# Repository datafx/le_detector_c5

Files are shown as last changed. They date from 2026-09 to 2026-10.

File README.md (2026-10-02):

# LE Gear Detector — XIAO ESP32-C5 Fork

Passive 5GHz/2.4GHz WiFi + BLE scanner for law-enforcement equipment,
rebuilt for the Seeed XIAO ESP32-C5 to add 5GHz detection. The original
project ([`datafx/le_detector`](https://github.com/datafx/le_detector),
ESP32-WROOM-32U) is 2.4GHz only and can't see the highest-value target
found in the field: Axon Fleet Hub units broadcasting their own hidden APs
on 5GHz. A match signals with a flashing red screen border + buzzer,
faster as the signal strengthens.

## Hardware

| Part | Notes | Link |
|---|---|---|
| Seeed Studio XIAO ESP32-C5 | RISC-V, dual-band WiFi 6 (2.4+5GHz), BLE 5, USB-C | [Seeed Studio](https://www.seeedstudio.com/Seeed-Studio-XIAO-ESP32C5-p-6609.html) |
| 2.8" ILI9341 TFT, SPI, 240×320, with XPT2046 touch + microSD slot | Standard combo board sold under many names; touch and SD are present on the board but not yet used by this firmware | search "2.8 inch ILI9341 SPI touch SD" |
| Active buzzer module, 3-pin (VCC/GND/signal) | Must have its own driver transistor onboard. Confirmed **active-low** on this build — check `BUZZER_ACTIVE_LOW` in `config.h` against yours | search "active buzzer module 3 pin" |
| Alfa APA-M25 dual-band antenna | 8 dBi @2.4GHz / 10 dBi @5GHz, RP-SMA | [Alfa Network](https://alfa-network.eu/apa-m25) |
| U.FL → RP-SMA pigtail | Connects the XIAO's onboard U.FL to the external antenna | search "U.FL RP-SMA pigtail" |
| Breadboard + jumper wires | | |
| USB-C cable | Power + programming | |

The display, buzzer, and pigtail are generic commodity parts sold by many
sellers under many names — there's no single canonical listing worth
linking (and one that works today can vanish tomorrow), so a search term
is given instead of a storefront link.

## Wiring

Pin assignments confirmed against the physical board — see `CLAUDE.md`
decision #6 for the full reasoning, including which pins were deliberately
avoided and why (boot-strap pins, reserved for a future GPS UART, etc.).

| Signal | XIAO pin | GPIO | Notes |
|---|---|---|---|
| Display `VCC` | `5V` | — | needs the 5V/VBUS pin specifically, not `3V3` |
| Display `GND` | `GND` | — | |
| Display `LED` (backlight) | `5V` | — | tied permanently on |
| Display `CS` | `D2` | 25 | |
| Display `DC` | `D3` | 7 | |
| Display `RESET` | `D4` | 23 | |
| Display `SDI`/MOSI | `D10` | 10 | shared SPI bus |
| Display `SCK` | `D8` | 8 | shared SPI bus |
| Display `SDO`/MISO | `D9` | 9 | shared SPI bus |
| `SD_CS` | `D5` | 24 | wired and reserved — SD support isn't built yet |
| `SD_MOSI`/`SD_MISO`/`SD_SCK` | `D10`/`D9`/`D8` | 10/9/8 | shared with the display |
| Buzzer `VCC` | `3V3` | — | |
| Buzzer `GND` | `GND` | — | |
| Buzzer signal | `D0` | 1 | |

Touch (`T_CLK`/`T_CS`/`T_DIN`/`T_DO`/`T_IRQ`) is present on the display
board but intentionally unwired — planned for future bench-configuration
tooling, not for driving controls.

## Build & flash

PlatformIO has no ESP32-C5 support as of this writing — this project
builds via the Arduino IDE / `arduino-cli` instead.

### Arduino IDE

1. **Install the ESP32 board package.** File → Preferences → Additional
   Boards Manager URLs, add:

       https://raw.githubusercontent.com/espressif/arduino-esp32/gh-pages/package_esp32_index.json

   Then Tools → Board → Boards Manager, search "esp32", install **esp32 by
   Espressif Systems**, version **3.3.5 or higher** (built and tested
   against 3.3.11).

2. **Select the board:** Tools → Board → esp32 → **XIAO_ESP32C5**.

3. **Install libraries** via Library Manager: `Adafruit GFX Library`,
   `Adafruit BusIO`, `Adafruit ILI9341`. BLE support is bundled with the
   esp32 core itself — no separate BLE library install needed.

4. **Open the sketch:** `firmware/le_detector_c5/le_detector_c5.ino`.
   Every `.cpp`/`.h` file in that same folder is compiled and linked
   automatically — Arduino sketches don't use PlatformIO's `src`/`include`
   split, so everything lives flat in one folder.

5. **Plug in the board** via USB-C, select its port, and upload.

### arduino-cli

    arduino-cli core update-index
    arduino-cli config set board_manager.additional_urls https://raw.githubusercontent.com/espressif/arduino-esp32/gh-pages/package_esp32_index.json
    arduino-cli core install esp32:esp32@3.3.11
    arduino-cli lib install "Adafruit GFX Library" "Adafruit ILI9341"
    arduino-cli compile --fqbn esp32:esp32:XIAO_ESP32C5 firmware/le_detector_c5
    arduino-cli upload -p /dev/ttyACM0 --fqbn esp32:esp32:XIAO_ESP32C5 firmware/le_detector_c5

### If upload fails, or the board doesn't show up as a serial port

The C5 uses its SoC's own native USB-Serial/JTAG peripheral, not a separate
USB-serial chip — no CH340/CP210x driver needed — but that comes with its
own gotchas, all hit and resolved during this project's own bring-up:

- **Linux: the `cdc_acm` kernel module.** If `/dev/ttyACM0` never appears,
  check `lsmod | grep cdc_acm`; if missing, `sudo modprobe cdc_acm` (if
  *that* fails with "module not found," your running kernel doesn't match
  what's installed on disk — reboot). Your user also needs permission on
  the port: group `dialout` on Debian/Ubuntu, `uucp` on Arch-based distros.
- **Upload fails with "Invalid head of packet" or "Serial data stream
  stopped: possible serial noise or corruption."** Looks like a code or
  board problem, usually isn't — a USB hub between the board and the
  computer was the actual cause here. Plug directly into a root/motherboard
  port before suspecting anything else.
- **No serial monitor output.** `arduino-cli monitor` produced nothing in
  testing even with the board clearly running. On Linux, plain
  `cat /dev/ttyACM0` worked reliably instead, and conveniently triggers a
  fresh reset on open. This firmware doesn't print anything during normal
  operation anyway (the display is the real status output), so this mostly
  matters if you're debugging.

## Watchlist

**62 OUI entries** across law-enforcement radio, body/dash cam, vehicle
router/MDT, radar/lidar, ALPR, and lightbar equipment, plus **6 SSID
patterns** (5 real + one test/demo row). The full list, provenance, and
vendor-collision reasoning live as comments in the source files themselves
— those are what actually runs, so they're the version that can't drift out
of sync with reality:

- [`oui_table.cpp`](firmware/le_detector_c5/oui_table.cpp) — MAC OUI
  watchlist
- [`ssid_table.cpp`](firmware/le_detector_c5/ssid_table.cpp) — SSID
  watchlist (beacons, probe requests, probe responses)

A few vendors are **disabled by default** after field testing showed they
false-positive more than they help — commented out, not deleted, so each
is one edit away from re-enabling if that read ever turns out wrong:
**CradlePoint**, **Peplink**, **Pepwave**, **Vantiva**, **PRO-VISION**.
Comment a row back in (or out) to change what's active for most entries;
CradlePoint specifically is gated by an `EXCLUDE_VENDOR_CRADLEPOINT` toggle
at the top of `oui_table.cpp`. Run `test/test_oui.cpp` after any edit.

Want to test a local addition before submitting it upstream? Drop it in
`user_oui_table.cpp` instead — unsorted, just appended to.

### SSID watchlist

| Pattern | Label | Category |
|---|---|---|
| `PSP-MVR` | PSP in-car video | Body/car cam |
| `SP-MVR` | PSP paired virtual AP | Other |
| `PSP-TEST` | PSP facility | Other |
| `PSPWLAN` | PSP facility | Other |
| `PSP_UC` | PSP facility voice | Other |
| `LEDET-TEST` | TEST/DEMO — not real gear | Other |

All PSP rows are prefix matches, deliberately — a substring `CONTAINS
"PSP"` rule tested against real survey data matched several unrelated
civilian networks near the same facilities (a pet store, a retailer, a
private residence). The full prefix string, not the shared `PSP` fragment,
is what makes these safe to alert on. Same logic for `SP-MVR` vs.
`PSP-MVR`: kept as two explicit rows rather than one `CONTAINS "SP-MVR"`
rule, which would also match `PSP-MVR` (it contains "SP-MVR" as a
substring).

**Provenance:** confirmed via WiGLE survey data cross-checked against
three independent Pennsylvania State Police barracks in three different
troops, roughly 280km apart, all on matching Cisco hardware.
`PSP-MVR`/`SP-MVR` (Mobile Video Recorder, PSP's in-car video system) and
`PSP-TEST` were confirmed at all three sites; cross-site BSSID correlation
— matching Cisco OUI sub-ranges across independently surveyed locations,
not just a shared naming convention — confirms a single statewide
deployment, not coincidence. `PSPWLAN`/`PSP_UC` were observed at one site
only, so carry lower confidence until cross-checked elsewhere. Exact survey
locations and dates are kept in local, non-public notes rather than this
file.

**Known limitation:** these are fixed APs at barracks buildings, not
vehicle-mounted equipment. A hit on the road means a cruiser's in-car
client is directedly probing for one of these SSIDs while out of range of
the real AP — whether PSP in-car systems actually do that is untested in
the field. Treat a hit here as barracks-proximity, not confirmed mobile
detection, until that's verified.

## How detection works

A three-band phase machine — only one of WiFi-5GHz / WiFi-2.4GHz / BLE can
be up at a time (one radio behind a dual-band diplexer, and it can't do
WiFi and BLE simultaneously either). Scheduling is 5GHz-dominant, based on
real drive data and a measured radio-switch cost on this specific board:

- **5GHz** sweeps continuously (9 non-DFS channels, ~2.7s/sweep) — the
  only long-range, continuous signal (beacons every ~100ms), and the
  primary detection path.
- **BLE** gets a short 400ms dip every 3rd 5GHz sweep, not every cycle —
  its realistic job is a close/stopped encounter lasting several seconds,
  not a sub-second highway pass, so it doesn't need constant attention.
- **2.4GHz** gets a brief 3-channel token check (1/6/11 only) every 8th
  sweep — contributes almost nothing on the road per the drive data (a
  barracks-proximity signal, not a mobile one), kept only as an occasional
  check.

Measured WiFi↔BLE switch cost on this board: **103ms** to switch into BLE,
**9ms** back out, with zero measured variance across repeated runs. See
[`firmware/05_radio_switch_timing/`](firmware/05_radio_switch_timing/) to
re-measure on different hardware. The "every N sweeps" cadence constants
(`BLE_EVERY_N_SWEEPS`, `WIFI_2G_EVERY_N_SWEEPS` in `config.h`) are starting
points to tune empirically, not a measured optimum.

A match's alert shows which band/radio caught it — e.g. "via 5GHz WiFi
OUI" or "SSID beacon (2.4GHz): PSP-MVR" — useful for telling a long-range
hit apart from a close BLE encounter at a glance.

## Known limits

- **One radio, three bands, time-sliced.** Only one of 5GHz WiFi / 2.4GHz
  WiFi / BLE is ever listening — during any other phase, that band is
  invisible. See "How detection works" above for the current schedule.
- **MAC randomisation.** Only public BLE addresses and non-randomised WiFi
  MACs carry a real OUI — randomised addresses are skipped, since their
  vendor bits are meaningless. SSID matching runs independently of this
  and is unaffected.
- **PSP SSID rows are barracks-proximity, not confirmed mobile detection.**
  See SSID watchlist provenance above.
- **SSID matching depends on what's actually broadcast.** A wildcard probe
  or hidden-SSID beacon carries no SSID bytes at all — nothing to match
  either way. Directed probe requests are a declining signal on modern
  phones (randomised MAC + wildcard probes only, roughly iOS/Android 2014-
  2017 onward), so this increasingly only catches older/embedded clients.
  Beacon/probe-response matching is unaffected by that trend.
- **No SD card support yet.** The display board has a microSD slot and the
  select pin (`SD_CS`) is wired, but CSV-based config/logging isn't built —
  the firmware runs entirely on its compiled-in tables for now.

## Tuning

Everything lives in `firmware/le_detector_c5/config.h`: band/channel
lists, sweep cadence, flash-rate endpoints (`RSSI_WEAK`/`RSSI_STRONG`,
`FLASH_PERIOD_SLOW`/`FAST`), alert hold time, and `BUZZER_ENABLED` for
silent bench testing.

## License

GPLv3 (see `LICENSE`), matching the companion `rf_stalker` and
`police_oui_watchlist` projects, and the upstream `le_detector` project
this is forked from.

[`firmware/le_detector_c5/detector.cpp`](firmware/le_detector_c5/detector.cpp)
carries its own `SPDX-License-Identifier: MIT` line for the portions
adapted from nyanBOX — see the header comment in that file for exactly
what was adapted and what changed. Everything else in this repo is GPLv3.

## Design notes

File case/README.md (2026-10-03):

# Case — WORK IN PROGRESS, NOT FINAL

3D-printable enclosure (Tinkercad export), built and tested with the
display/XIAO/buzzer wired via breadboard jumpers — confirmed everything
fits and works, but this is not the final case.

- `Extended_case.stl` / `Lid.stl` — current working revision.
- **Width and height are final** (matched to the display's own 50×86mm
  board, with the lid already cut with a viewing window for it).
- **Depth will be shortened** once the carrier PCB (see
  `../hardware/carrier_pcb/`, also still WIP) is finished and the actual
  component stack height is known — the current depth has far more
  clearance than needed.

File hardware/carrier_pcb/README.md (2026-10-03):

# Carrier PCB — WORK IN PROGRESS, NOT FINISHED

Do not fabricate this board as-is. Schematic, footprint layout, and
routing are all DRC-clean (0 errors, 0 unconnected items) - routing was
redone from scratch after U1's footprint was corrected (see below), and
solder-side correctness for all 4 connectors was verified directly from
the footprint layer data, not just visually. Still no physical test-fit
of the current board size - see "What's NOT done."

## Mounting: held by the header, not screwed to the case

This board has **no mounting holes**. Earlier drafts gave it the same 4
holes as the display module, so it could bolt to the case's existing
corner bosses — but that only works by stacking both boards on the same
4 screws, which needs standoffs/spacers between them and a case
modification to deepen the bosses. Given how light this assembly is
(PCB + XIAO + buzzer), that's not worth it: the board is instead held
purely by its header engagement with the display board above it (which
keeps screwing to the case exactly as it did before this board existed).
If real-world vibration ever proves that insufficient, a dab of hot glue
between the two boards is the cheap fix — not designed in up front.

**History: chamfer → notch → narrowed board, each one fitting the real
case better than the last.** The first version used a 6mm diagonal
chamfer at each corner, sized off the display's datasheet hole margins
with no real measurement of the boss itself. A 1:1 scale printout
test-fit against the real case showed it wasn't close - the boss is a
rounded square, not the slim post the chamfer assumed. Measured it
properly off the case STL (top-down render, self-calibrated against the
model's own exact bounding box, not an assumed scale): roughly **7-8mm
across**. Switched to a square notch sized as large as the layout
allowed (7.3mm, capped by J1's own pad clearance) - still about 1mm
short of what the boss needed, an acknowledged unresolved gap at the
time.

**Resolved differently: don't dodge the bosses, don't reach them at
all.** User measured the case's actual clear channel between the two
bosses directly: **36.3mm wide** (the board's full 86mm length is fine,
the case was never tight there). The board became a **plain rectangle,
36.3mm × 86mm**, centered on J1 (which is the single widest feature at
33.02mm) rather than matching the display's full 50mm width. This
sidesteps the boss problem entirely instead of cutting around it - no
corner notches needed, and it also incidentally resolved a DRC
clearance warning on a user-routed TFT_SCK trace that had been sitting
close to the old, bigger notch. J1 keeps 1.04mm of copper-to-edge
clearance on each side (comfortably above the 0.5mm minimum), and J2/U1/
J3 were already well inside this narrower footprint with no changes
needed.

**Trimmed again: top edge pulled in to put J2 right on the edge too,
mirroring J1.** J1 sits 2.0mm (pin-center-to-edge) from the bottom edge.
J2 was still 4.96mm from the top edge, leaving unused board above it.
Pulled the top edge in to the same 2.0mm margin: new top edge at
**y=2.96** (was y=0), so the board is now **36.3mm × 83.04mm**. J2 gets
the same 1.40mm copper-to-edge clearance J1 already had. Both edits
(width and this height trim) were applied by editing the outline
directly in the routed file rather than regenerating from the script,
each time confirming no existing trace/via fell outside the new
boundary before committing to it - preserved all 64 of the user's
hand-routed segments through both changes, verified via DRC (0 errors)
each time.

**Still not physically confirmed** - this is a digital fit against the
user's own case measurement, not yet a hands-on test with the actual
board at its current size. Print and test-fit again before fabricating.

## U1 (XIAO socket): footprint was wrong, now matches the real device

The original U1 footprint was a generic guess — two rows of 7 pins,
7.62mm apart, pins at `i*2.54mm` within each row — never checked against
the real XIAO ESP32-C5's actual pinout, and not mirrored for back-side
mounting. User caught both problems: wrong footprint, and backwards for
how the device actually gets plugged in (XIAO mounts on the board's
back, opposite the display).

**Fixed using Seeed's own official files**, not another guess:
downloaded their published KiCad footprint
(`XIAO-ESP32-C5-DIP.kicad_mod`) and schematic symbol from the
[XIAO KiCad library](https://wiki.seeedstudio.com/XIAO_BLE/) (same
family covers every XIAO board). The real footprint has **15.24mm**
between the two pin rows, not 7.62mm — a completely different part of
the board was being used. Cross-referenced the symbol to get the
real pin-number-to-signal mapping (D0–D6 on one row, D7–D10 + 3V3_OUT/
GND/VBUS on the other, in that specific order — not a clean split).

**Mirroring**: a part mounted on the back layer needs its footprint
mirrored left-right relative to how it would sit on the front — this is
what KiCad does automatically when you flip a footprint in the GUI, but
since this one was hand-authored as raw coordinates, that mirroring had
to be applied by hand too, and wasn't. Verified the mirror direction
using Seeed's own front and back pinout diagrams for the XIAO (they
publish both specifically because this flip is easy to get backwards) -
confirmed the two diagrams are exact left-right mirrors of each other
before trusting the derivation.

**Routing cleared, not preserved, for this one.** Unlike the earlier
outline-only changes (width, height trims), this moves the pads
themselves, and nearly every net touches U1 directly or routes through
it - preserving any of the old routing wasn't realistic. Pulled all 64
track/via segments rather than leave something uncertain in place.
Board is back to a clean, DRC-verified ratsnest (0 errors, 12
unconnected items, matching the exact pre-routing baseline) - **needs a
full re-route**.

**Slid toward the board's right edge** for USB-C cable clearance, as
far as the *real device's physical body* allows - not just its pads.
The pads alone would have permitted sliding further right, but the
actual XIAO module extends ~2.8mm beyond its own pin span on each side;
checking pads only would have let the real part hang ~1.3mm off the
board edge. Capped at **x=32** (board right edge minus the real
courtyard extent minus a 0.5mm margin), not x=34.

**Flagging, not deciding, one open question**: with this as a straight
slide (no rotation), the XIAO's USB-C port faces *inward* (toward
x≈21-23, the board's open left-center area), not toward the right edge
itself - it's the *blank far end* of the device that now sits near the
right edge. This still frees up real approach space for a cable (the
whole left side of U1's row is now open board), but if the port itself
needs to be at/past the edge, that needs a 180° rotation on top of the
slide, which hasn't been done - flagging it rather than guessing, since
it changes which end of the board needs clearance.

## J3 (buzzer socket): pin order changed, moved left, now a right-angle header

**Pin order**: was VCC/GND/SIG (pins 1/2/3). Changed to **GND/SIG/VCC**
(pins 1/2/3) to match the physical pinout of the actual buzzer module
being used. Schematic symbol's pin names updated to match (so the
symbol doesn't show "pin 1 = VCC" while actually wired to GND) - J3's
physical pad *positions* didn't change for this part, only which net
each pad carries.

**Position**: moved from x=20 to **x=9** (pins span 9.00-14.08), clear
of both the board's left edge (1.55mm pad clearance) and U1's real
device body (6.77mm clear of U1's courtyard at x≈21.45) - U1 having
moved right made room for this.

**Right-angle (90°) header, not straight** - so the buzzer module can
lie flat against the back of the carrier instead of standing up
perpendicular on pins. This is a BOM/part-choice change, not a PCB
layout change: a right-angle header's hole pattern is the same 3 pads
at the same pitch, just a different physical part populated there -
reflected in `BOM.md`, `bom.csv`, and the schematic's own description
field for J3.

**Standoff height: not chosen - a real open question, not a guess I'm
comfortable making.** The buzzer board needs to lie flat without
touching a USB-C cable plugged into U1's port. Getting that number
right needs several real measurements I don't have verified: U1's own
header standoff height (never specified - it's just "a 2x7 female
header" with no particular part/height chosen either), the XIAO's USB-C
receptacle height above its own PCB (datasheet has no Z-axis dimension,
only the 21x17.8mm footprint), and critically, **the actual cable's
plug profile** - which isn't a XIAO spec at all, it varies by which
cable gets used, from slim low-profile plugs to bulky ones. A header
spec sheet can't tell me that part. **Recommend a physical mockup**
once the real parts are in hand (XIAO + a header + the actual cable
likely to be used) rather than trusting a number derived from
incomplete datasheets - or tell me the exact cable/header part numbers
if there's a specific one in mind and I can look up real dimensions for
those two at least.

## J2 (SD header socket): populated, not wired

J2 is on the board purely so the display module has somewhere to plug
its SD header into for mechanical support — pulling one corner of the
display without it would leave that corner unsupported by anything but
J1. It carries **no electrical connections**: all 4 pins (and U1's
SD_CS pin, which would otherwise drive it) are explicit no-connects.
SD card bring-up (mount, read, CSV config/logging) is a real future
goal, not abandoned, but it's down the road enough that wiring it now
would just be unused complexity - revisit as part of a later PCB
revision, likely alongside touch support.

**The display doesn't come with a header there to plug in** - the
MSP2807's SD pads ship unpopulated (confirmed from the datasheet). A
1×4 male header needs to be hand-soldered onto the display board itself
before it has anything to mate with J2 - added to `BOM.md`.

**Position re-measured and corrected.** The first placement (18.40,
11.00) was a rough visual estimate. Re-measuring the datasheet image
found the estimate was based on an incorrect pixel-to-mm scale (assumed
a literal 1:1 300dpi-to-mm render; the PDF's actual scale, derived from
the two known hole-spacing dimensions, is ~9.05px/mm, not ~11.81).
Corrected position: **(21.15, 4.96)** — the 4 SD pads sit at essentially
the same height as the top mounting holes, not ~11mm down as first
estimated. Pitch was already right (standard 2.54mm). Still a datasheet
*image* measurement, not a direct physical check — reasonably confident
now, but confirm against the real board before fabricating.

## Silkscreen: functional labels, pin-1 markers, and a real bug fixed

Added on request - before this, silkscreen was just 4 bare reference
designators (J1/J2/J3/U1), nothing else, no graphics at all.

- **Functional labels** on all 4 connectors, stating what they are *and*
  which side of the board the part goes on: `DISPLAY — FRONT` (J1),
  `SD (NC) — FRONT` (J2), `XIAO — BACK` (U1), `BUZZER — BACK` (J3).
- **Pin-1 markers**: pin 1 of every connector is now a square pad
  instead of round (standard convention) - J2 and J3 didn't strictly
  need it since they're asymmetric/small, but did it for all 4 for
  consistency and because this board has already had two real
  orientation bugs this session (U1's mirroring, J3's pin order) - cheap
  insurance against a third one during assembly.
- **Board title**: `LE Detector C5 by datafx`, 2.2mm text (noticeably
  larger than the 1mm connector labels), vertical along the left edge,
  top-justified. Placed on the back (B.SilkS) rather than the front -
  the display covers nearly the full front face once plugged into J1
  (its own board is as tall as this carrier, header near its bottom
  edge), so front silkscreen would be hidden after assembly; the back
  stays mostly open even with U1/J3 populated. Positioned clear of both
  U1 and J3, confirmed via DRC and a true flipped-back render (not just
  the see-through view) before trusting it, per the mirroring lesson
  just below.

**Found and fixed a real bug while verifying this, not a new one
introduced by it: back-layer silkscreen text was never actually
mirrored.** DRC has been flagging `nonmirrored_text_on_back_layer` on
U1's and J3's reference labels since they were first created, and it
was dismissed every single time as the same cosmetic baseline as the
`lib_footprint_issues` warnings - it isn't. Rendered the board with
`kicad-cli`'s `-m` flag (true "physically flip the board and look at
the back" view, not the usual "see-through from the front" renders used
throughout this project) and the text came out genuinely backwards -
`U1`, `J3`, and both new back-side labels all read right-to-left,
garbled. This would have printed wrong on the real board. Fixed by
adding `(justify mirror)` to all 4 back-layer text elements (the 2
existing reference labels plus the 2 new functional labels) - verified
again with the same true-flip render, now reads correctly. **Re-check
any future back-layer text added to this board the same way** (render
with `-m`, don't trust the normal see-through view) - this bug is easy
to reintroduce since hand-authored S-expressions don't get KiCad's
automatic GUI-flip mirroring for free.

## What's done and verified

- **Schematic** (`carrier_pcb.kicad_sch`) — complete, ERC-clean (0 errors).
  Every net matches the locked pin table in the project's own notes.
- **PCB footprint placement** (`carrier_pcb.kicad_pcb`) — board outline
  (36.3×83.04mm rectangle, see above) and the display's main header
  position taken directly from the MSP2807 display's own datasheet, not
  estimated. DRC-verified: every pad is on the correct net
  (ratsnest-correct), 0 real errors.
- **U1 footprint** now matches Seeed's official XIAO-ESP32-C5-DIP
  footprint, correctly mirrored for back-side mounting (see above).
- **Silkscreen** — functional labels + pin-1 markers on all 4
  connectors, back-layer text verified correctly mirrored (see above).
- **Routing** — redone from scratch in the KiCad GUI after U1's
  footprint was corrected. DRC clean: 0 errors, 0 unconnected items.
- **Solder side for all 4 connectors** — verified directly from each
  footprint's stored layer field (not just visually): J1/J2 on `F.Cu`
  (front), U1/J3 on `B.Cu` (back), matching their silkscreen labels.

## What's NOT done

- **SD header position** (J2) is re-measured and corrected (see above)
  but still a datasheet-image measurement, not a direct physical check —
  verify against the physical display board before finalizing.
- **No future USB-C panel connector or pigtail** designed yet — the case
  already has a wire-passthrough cutout reserved for this, but the
  connector and cable routing aren't part of this board yet.
- **No physical test-fit yet** against the real case/display with the
  *current* (narrowed) outline — sized against the user's own case
  measurement (36.3mm clear channel), not yet confirmed hands-on with
  the actual board.

## Fits the case in `../../case/` (also WIP — see its README)

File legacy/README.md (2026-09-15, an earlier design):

Original ESP32 / 2.4 GHz-only / u8g2-OLED implementations of `detector.cpp`,
`ui.cpp`, `main.cpp`, and `config.h`, carried over from `le_detector` for
reference only. These need a genuine rework for the XIAO ESP32-C5 (5 GHz
support, three-band phase machine, ILI9341 colour UI, SD-backed config) per
the root `CLAUDE.md` — not a port. Do not build against this directory.

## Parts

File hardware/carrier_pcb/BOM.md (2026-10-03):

# Carrier PCB — Bill of Materials

## Parts to populate on the carrier PCB

Generated from the schematic (`kicad-cli sch export bom`) — see `bom.csv`
for the raw export.

| Ref | Qty | Description |
|---|---|---|
| J1 | 1 | 1×14 female header, 2.54mm pitch — socket for MSP2807 display main header |
| J2 | 1 | 1×4 female header, 2.54mm pitch — socket for MSP2807 SD header (**mechanical only, not wired** — see README) |
| J3 | 1 | 1×3 **right-angle (90°)** female header, 2.54mm pitch — socket for 3-pin active buzzer module, lets the buzzer board lie flat against the carrier instead of standing up on pins. **Standoff height not yet chosen** — must clear a USB-C cable plugged into U1, see README. |
| U1 | 1 | 2×7 female header, 2.54mm pitch — socket for Seeed XIAO ESP32-C5 |

## Mounting hardware

None. This board isn't screwed to the case — it's held by the header
engagement with the display board above it, which keeps its own original
4 screws/standoffs into the case's corner bosses unchanged. A dab of hot
glue between the carrier PCB and the display board is the fallback if
testing ever shows the header connection alone isn't enough — not
included here since it's a maybe-needed-later item, not a planned part.

## Plug-in modules (not populated on the carrier PCB)

These mate with the sockets above rather than being soldered to the
carrier board. Already documented with sourcing links in the project
[README](../../README.md#hardware) — not duplicated here to avoid two
copies drifting out of sync:

- Seeed Studio XIAO ESP32-C5 → plugs into U1
- MSP2807 2.8" display module → plugs into J1 + J2 (see below — J2's
  side needs a header added to the display board itself first)
- 3-pin active buzzer module → plugs into J3

## Parts needed on the display module itself (not included with it)

| Part | Qty | Notes |
|---|---|---|
| 1×4 male header, straight, 2.54mm pitch | 1 | The MSP2807 ships with its SD-header pads **unpopulated** — confirmed from the datasheet, this isn't a stock part of the board. Hand-solder one onto those pads so the display has pins to plug into J2. Purely mechanical (J2 carries no signals — see README); any 1×4 straight male header works, doesn't need to match any particular spec beyond 2.54mm pitch to fit the pads. |

## Not yet in this BOM

- Future USB-C panel-mount connector + internal pigtail cable (per the
  wire-passthrough cutout already in the case) — not designed yet.

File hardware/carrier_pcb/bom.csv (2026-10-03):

Reference | Value | Description | Qty
J1 | DISPLAY_MAIN | 1x14 female header, 2.54mm pitch - socket for MSP2807 display main header | 1
J2 | DISPLAY_SD | 1x4 female header, 2.54mm pitch - socket for MSP2807 SD header (mechanical only - not wired, see README) | 1
J3 | BUZZER | 1x3 RIGHT-ANGLE (90-degree) female header, 2.54mm pitch - socket for 3-pin active buzzer module, lets the buzzer board lie flat - standoff height must clear a USB-C cable plugged into U1, see README | 1
U1 | XIAO_ESP32C5 | 2x7 female header, 2.54mm pitch - socket for Seeed XIAO ESP32-C5 | 1

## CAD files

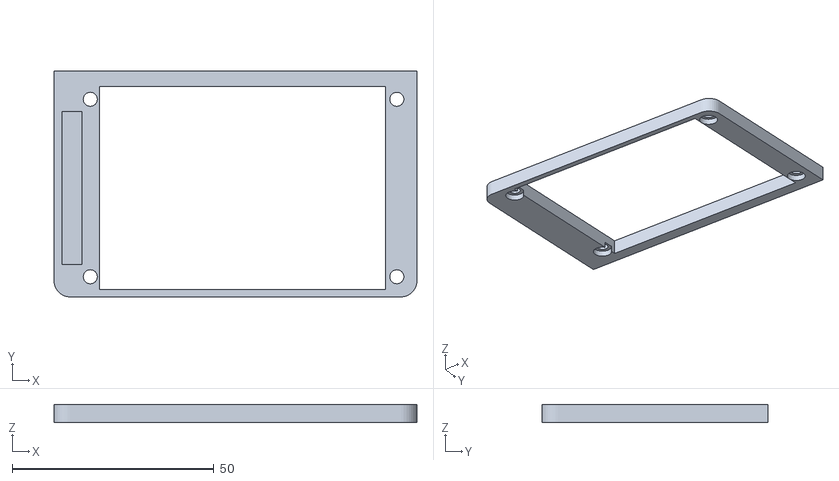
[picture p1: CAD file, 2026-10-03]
case/Lid.stl
90.0 x 56.0 x 4.50

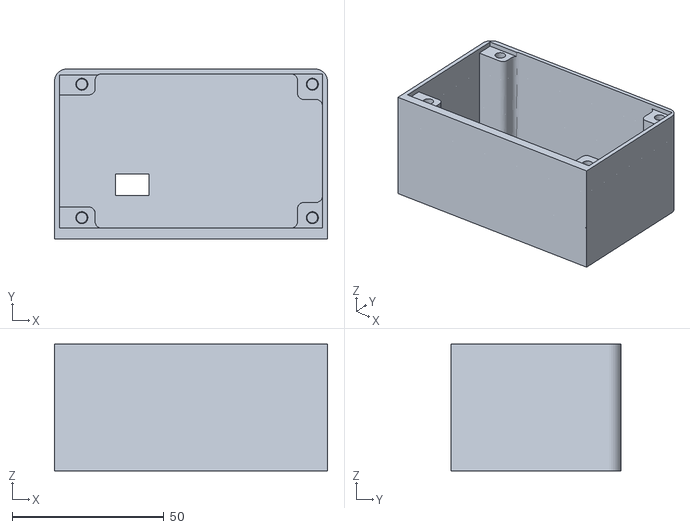
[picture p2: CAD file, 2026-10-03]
case/Extended_case.stl
90.0 x 56.0 x 41.8

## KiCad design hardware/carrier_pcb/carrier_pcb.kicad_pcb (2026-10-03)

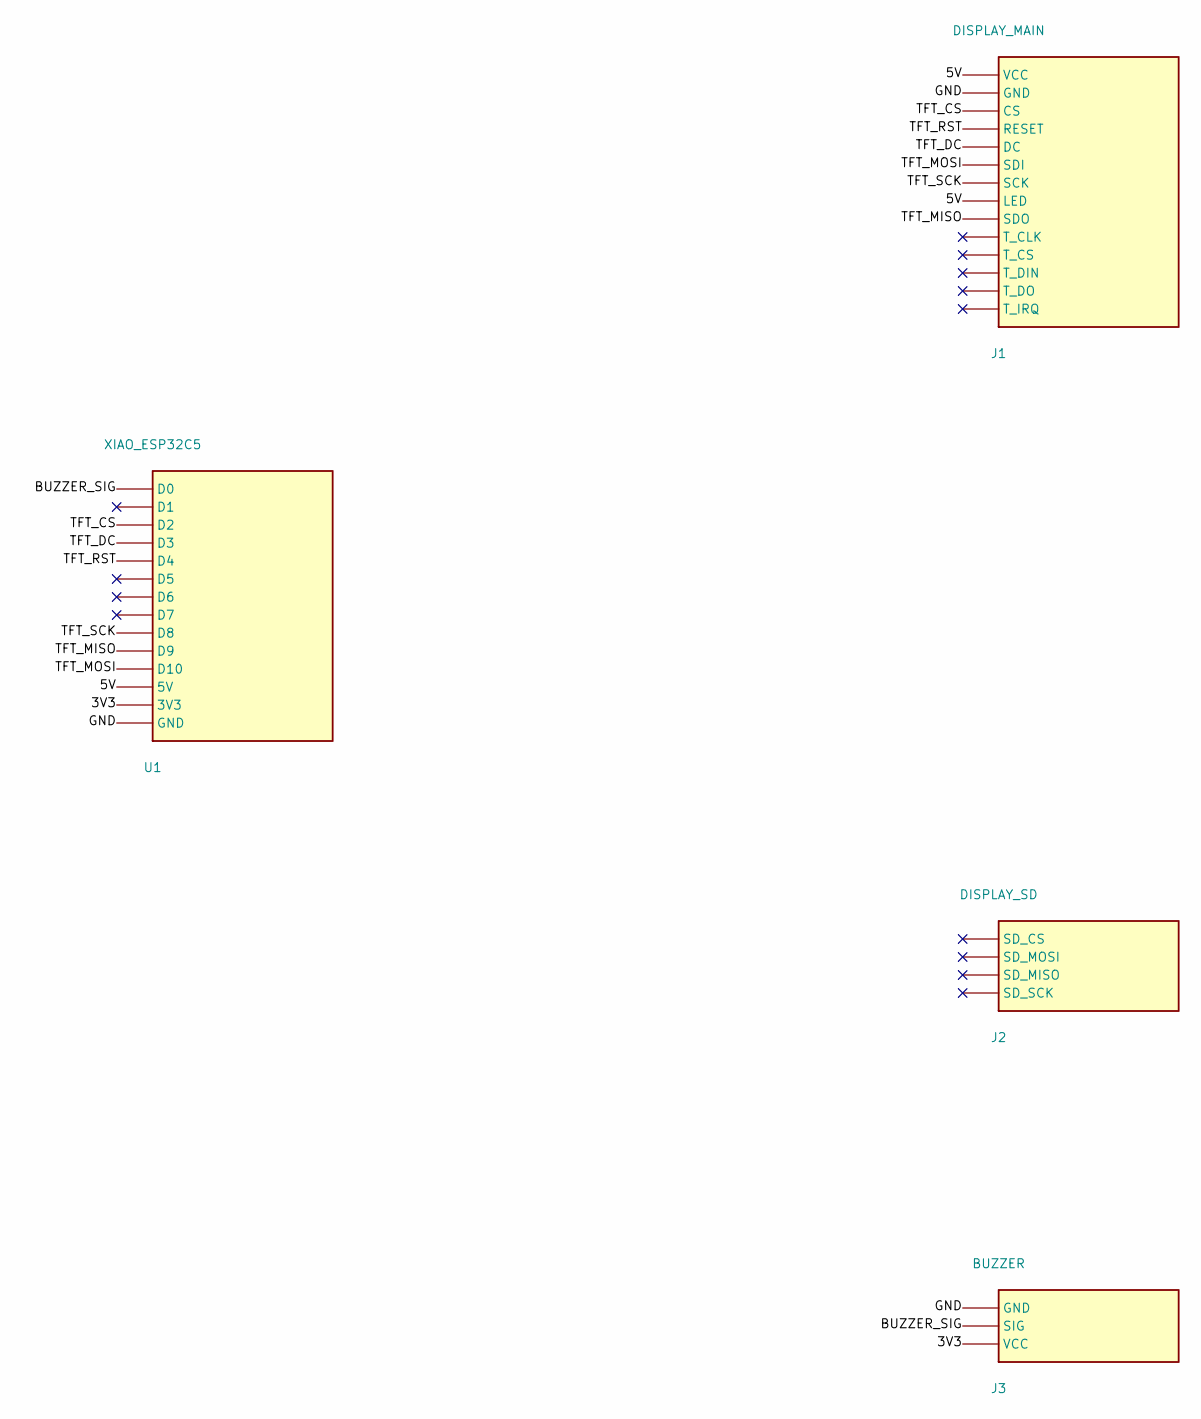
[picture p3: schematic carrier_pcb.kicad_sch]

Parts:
J1: DISPLAY_MAIN
J2: DISPLAY_SD
J3: BUZZER
U1: XIAO_ESP32C5

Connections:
3V3: J3.3 (VCC), U1.13 (3V3)
5V: J1.1 (VCC), J1.8 (LED), U1.12 (5V)
BUZZER_SIG: J3.2 (SIG), U1.1 (D0)
GND: J1.2 (GND), J3.1 (GND), U1.14 (GND)
TFT_CS: J1.3 (CS), U1.3 (D2)
TFT_DC: J1.5 (DC), U1.4 (D3)
TFT_MISO: J1.9 (SDO), U1.10 (D9)
TFT_MOSI: J1.6 (SDI), U1.11 (D10)
TFT_RST: J1.4 (RESET), U1.5 (D4)
TFT_SCK: J1.7 (SCK), U1.9 (D8)

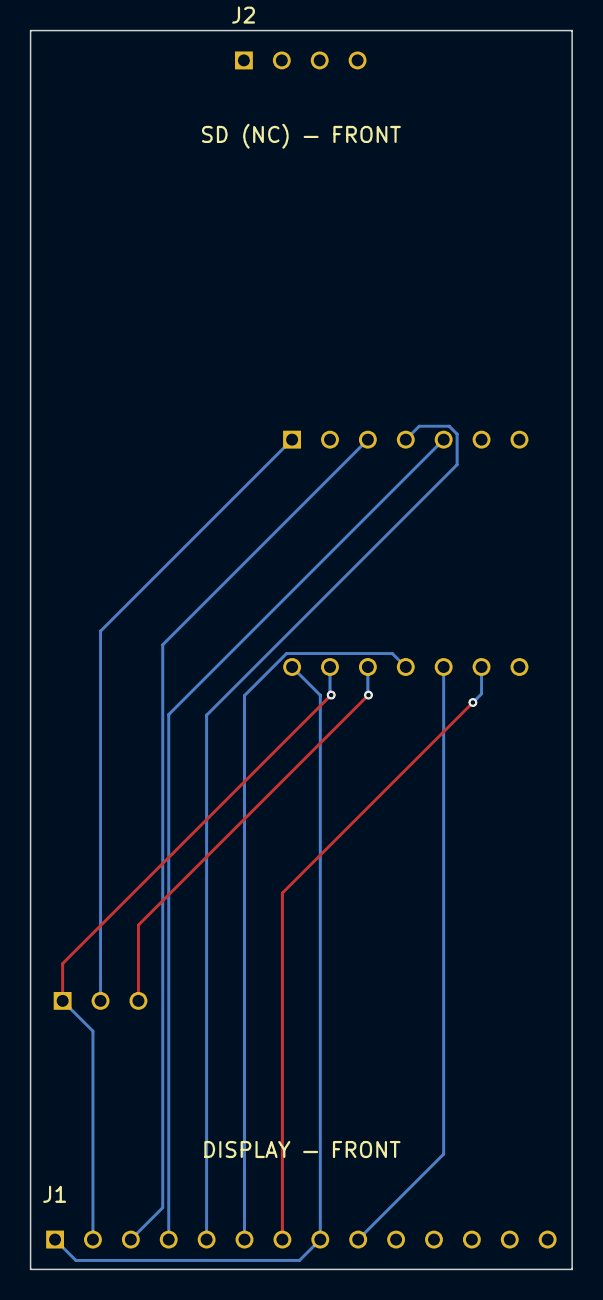
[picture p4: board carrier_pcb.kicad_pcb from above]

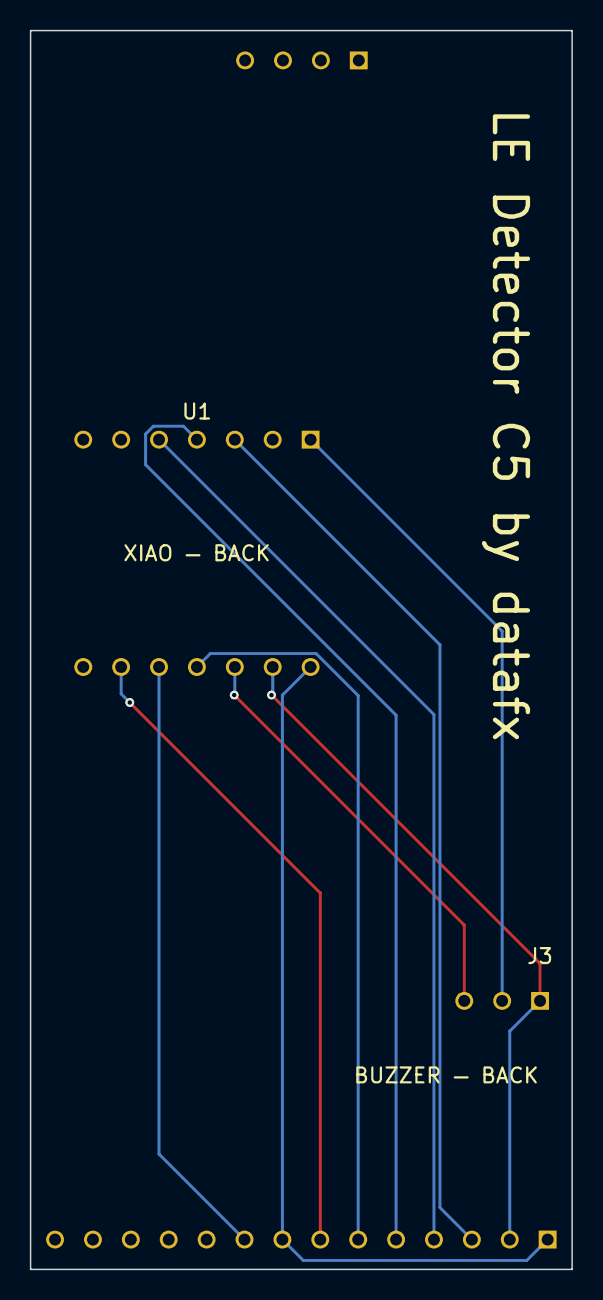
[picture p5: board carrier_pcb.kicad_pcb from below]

Board: 2 copper layers, 36.3 x 83.0 mm, 4 parts (2 on the bottom side), 10 nets.

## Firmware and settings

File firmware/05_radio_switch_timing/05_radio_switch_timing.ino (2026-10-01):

// Measures real radio-switch overhead using the actual detector.cpp phase
// functions (not a reimplementation) - this is exactly what production
// code pays every time it switches bands. Also checks whether
// esp_wifi_set_channel accepts DFS channels (52-140) in promiscuous/STA
// mode on this core, which decides whether a "rare DFS dip" tier is even
// possible.
//
// Results go to the display, not serial - BLE radio activity appears to
// disrupt the native USB-Serial/JTAG connection (captures kept getting cut
// off right around BLE init), so the screen is the reliable channel here.

#include "detector.h"
#include "esp_wifi.h"
#include "config.h"
#include <stdarg.h>

#include <SPI.h>
#include <Adafruit_GFX.h>
#include <Adafruit_ILI9341.h>

static Adafruit_ILI9341 tft(PIN_TFT_CS, PIN_TFT_DC, PIN_TFT_RST);

static const int ITERATIONS = 8;

static uint32_t timeIt(void (*fn)()) {
  uint32_t start = millis();
  fn();
  return millis() - start;
}

static void doStopWifi()  { detectorStopWifiPhase(); }
static void doStartBle()  { detectorStartBlePhase(); }
static void doStopBle()   { detectorStopBlePhase(); }
static void doStartWifi() { detectorStartWifi5GPhase(); }

static void printLine(int16_t y, const char* fmt, ...) {
  char buf[64];
  va_list args;
  va_start(args, fmt);
  vsnprintf(buf, sizeof(buf), fmt, args);
  va_end(args);
  tft.setCursor(8, y);
  tft.print(buf);
  Serial.println(buf); // best-effort, may be lost to BLE/USB interaction
}

static void runTest() {
  uint32_t wifiToBleSum = 0, bleToWifiSum = 0;
  uint32_t wifiToBleMin = 0xFFFFFFFF, wifiToBleMax = 0;
  uint32_t bleToWifiMin = 0xFFFFFFFF, bleToWifiMax = 0;

  tft.fillScreen(ILI9341_BLACK);
  tft.setTextColor(ILI9341_WHITE);
  tft.setTextSize(2);
  printLine(8, "Radio switch timing");
  printLine(32, "Running %d iterations...", ITERATIONS);

  doStartWifi();
  delay(500);

  for (int i = 0; i < ITERATIONS; i++) {
    uint32_t tStopWifi = timeIt(doStopWifi);
    uint32_t tStartBle = timeIt(doStartBle);
    uint32_t wifiToBle = tStopWifi + tStartBle;
    wifiToBleSum += wifiToBle;
    if (wifiToBle < wifiToBleMin) wifiToBleMin = wifiToBle;
    if (wifiToBle > wifiToBleMax) wifiToBleMax = wifiToBle;

    delay(500); // simulate a short BLE dwell

    uint32_t tStopBle  = timeIt(doStopBle);
    uint32_t tStartWifi = timeIt(doStartWifi);
    uint32_t bleToWifi = tStopBle + tStartWifi;
    bleToWifiSum += bleToWifi;
    if (bleToWifi < bleToWifiMin) bleToWifiMin = bleToWifi;
    if (bleToWifi > bleToWifiMax) bleToWifiMax = bleToWifi;

    printLine(56 + i * 20, "i%d W>B=%lu B>W=%lu", i, wifiToBle, bleToWifi);

    delay(500); // simulate a short WiFi dwell before next switch
  }

  // --- DFS channel tunability check (WiFi already up, 5GHz) ---
  const uint8_t dfsChannels[] = {52, 100, 140};
  bool dfsOk[3];
  for (int j = 0; j < 3; j++) {
    esp_err_t err = esp_wifi_set_channel(dfsChannels[j], WIFI_SECOND_CHAN_NONE);
    uint8_t primary = 0;
    wifi_second_chan_t second;
    esp_wifi_get_channel(&primary, &second);
    dfsOk[j] = (err == ESP_OK) && (primary == dfsChannels[j]);
  }
  esp_wifi_set_channel(149, WIFI_SECOND_CHAN_NONE); // leave on a known-good channel

  tft.fillScreen(ILI9341_BLACK);
  printLine(8,  "=== RESULTS ===");
  printLine(32, "WiFi->BLE avg=%lums", wifiToBleSum / ITERATIONS);
  printLine(52, "  min=%lu max=%lu", wifiToBleMin, wifiToBleMax);
  printLine(76, "BLE->WiFi avg=%lums", bleToWifiSum / ITERATIONS);
  printLine(96, "  min=%lu max=%lu", bleToWifiMin, bleToWifiMax);
  printLine(120,"Round-trip avg=%lums", (wifiToBleSum + bleToWifiSum) / ITERATIONS);
  printLine(152,"DFS ch52=%s ch100=%s ch140=%s",
            dfsOk[0] ? "OK" : "FAIL", dfsOk[1] ? "OK" : "FAIL", dfsOk[2] ? "OK" : "FAIL");
  printLine(180,"Repeating in 20s...");
}

void setup() {
  Serial.begin(115200);
  delay(1000);
  detectorInit();

  SPI.begin(PIN_TFT_SCK, PIN_TFT_MISO, PIN_TFT_MOSI, PIN_TFT_CS);
  tft.begin();
  tft.setRotation(1);
  tft.fillScreen(ILI9341_BLACK);
}

void loop() {
  runTest();
  delay(20000);
}

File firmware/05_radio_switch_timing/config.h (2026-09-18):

// SPDX-License-Identifier: GPL-3.0-only
#pragma once
#include <Arduino.h>

// ---------------------------------------------------------------------------
// Hardware pins (decision #6 in CLAUDE.md - confirmed against physical board)
// ---------------------------------------------------------------------------
static const uint8_t PIN_TFT_CS   = 25;  // D2
static const uint8_t PIN_TFT_DC   = 7;   // D3
static const uint8_t PIN_TFT_RST  = 23;  // D4
static const uint8_t PIN_SD_CS    = 24;  // D5 (reserved, not read until SD bring-up)
static const uint8_t PIN_TFT_SCK  = 8;   // D8, shared SPI bus
static const uint8_t PIN_TFT_MISO = 9;   // D9, shared SPI bus
static const uint8_t PIN_TFT_MOSI = 10;  // D10, shared SPI bus
static const uint8_t PIN_BUZZER   = 1;   // D0

// No PIN_LED - the screen border flashes instead (decision: "No status LED").
// No PIN_BOOT - no physical buttons; config lives on the SD card (future).

// ---------------------------------------------------------------------------
// Radio scheduling - three-band phase machine
//
// The C5 has ONE radio behind a dual-band diplexer: it cannot listen to
// 2.4 and 5 GHz simultaneously, and still cannot do WiFi and BLE at once.
// So three phases, time-sliced, one radio stack up at a time.
//
// 5 GHz is weighted heaviest - the Axon Fleet Hub beacons continuously there
// and is the primary target found in the investigation. Channel list is the
// 9 non-DFS 5 GHz channels (36/40/44/48/149/153/157/161/165) rather than the
// full 36-165 range - DFS channels (52-144) need radar-detection handling
// this fork doesn't do yet, and every confirmed real-world target so far
// (Axon Fleet Hub, general enterprise gear) sits on non-DFS channels anyway.
// Revisit if that assumption doesn't hold up in the field.
// ---------------------------------------------------------------------------
static const uint8_t WIFI_5G_CHANNELS[]  = {36, 40, 44, 48, 149, 153, 157, 161, 165};
static const uint8_t WIFI_5G_CHANNEL_COUNT = sizeof(WIFI_5G_CHANNELS) / sizeof(WIFI_5G_CHANNELS[0]);
static const uint32_t WIFI_5G_PHASE_MS   = 4500;  // ~1.5 sweeps of 9 channels at 300ms hop
static const uint32_t WIFI_5G_HOP_MS     = 300;

// US 2.4GHz WiFi is FCC-licensed on channels 1-11 only; 12-13 are ETSI-region
// channels no US-market AP will legally beacon on, so scanning them is wasted
// dwell time.
static const uint8_t  WIFI_2G_MAX_CHANNEL = 11;
static const uint32_t WIFI_2G_PHASE_MS    = 3000;  // ~1 full sweep of ch 1-11, plus slack
static const uint32_t WIFI_2G_HOP_MS      = 250;

static const uint32_t BLE_PHASE_MS        = 3000;

// Passive = receive only, we never transmit. Set false only if you
// specifically want active BLE scanning (locked decision: stays passive).
static const bool BLE_SCAN_PASSIVE = true;

// ---------------------------------------------------------------------------
// Device tracking
// ---------------------------------------------------------------------------
static const uint8_t  MAX_TRACKED       = 48;    // fixed table, LRU eviction
static const uint32_t DEVICE_TTL_MS     = 10000; // drop entry if unseen this long
static const uint8_t  RSSI_EMA_NUM      = 1;     // EMA smoothing: new weight
static const uint8_t  RSSI_EMA_DEN      = 3;     //   value = (new*1 + old*2)/3

// ---------------------------------------------------------------------------
// Alert behaviour
//
// Screen border and buzzer are driven from a single phase so they are always
// in sync. Flash rate scales with the strongest active signal: weak = slow,
// strong = fast.
// ---------------------------------------------------------------------------
// Pure decay timer: resets to full duration on every qualifying receive
// (any matched device, not just the one that originally tripped the alert),
// never a latch. Three-phase mode needs enough slack to survive a full
// 5GHz->2.4GHz->BLE round trip plus missed-frame margin.
static const uint32_t ALERT_HOLD_MS       = 14000;

static const int8_t   RSSI_WEAK         = -95;   // maps to the slowest flash
static const int8_t   RSSI_STRONG       = -45;   // maps to the fastest flash
static const uint32_t FLASH_PERIOD_SLOW = 1000;  // ms, full on+off cycle
static const uint32_t FLASH_PERIOD_FAST = 150;

// Buzzer follows the border flash exactly, but capped so a fast flash chirps
// instead of droning. Set to a large value to make it perfectly 1:1.
static const uint32_t BUZZER_MAX_ON_MS  = 70;

// Set false to run silently (bench testing without the noise).
static const bool BUZZER_ENABLED = true;
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

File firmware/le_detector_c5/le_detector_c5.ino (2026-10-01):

/*
    LE Gear Detector - XIAO ESP32-C5

    Passive 5GHz/2.4GHz WiFi + BLE scanner that watches for OUIs and SSIDs on
    a law-enforcement-equipment watchlist and signals hits with a flashing
    screen border + buzzer, faster as the signal gets stronger.

    Three-band phase machine: the C5 has one radio behind a dual-band
    diplexer, so only one of WiFi-5GHz / WiFi-2.4GHz / BLE is ever up at a
    time. Reworked 2026-10-01 from a flat 5GHz->2.4GHz->BLE->repeat round
    robin to a 5GHz-dominant schedule, based on real drive data and a
    measured radio-switch cost (see config.h) - 5GHz sweeps continuously,
    with a short BLE dip and a rare 2.4GHz token check interleaved every few
    sweeps rather than every cycle. See config.h for the reasoning and the
    tunable constants.

    No physical buttons in this design (config lives on the SD card, not yet
    built - see CLAUDE.md) - the schedule always runs on its own, no manual
    override.
*/

#include <Arduino.h>
#include "config.h"
#include "detector.h"
#include "alert.h"
#include "ui.h"

enum Phase : uint8_t { PHASE_WIFI_5G, PHASE_WIFI_2G, PHASE_BLE };

static Phase    s_phase          = PHASE_WIFI_5G;
static uint32_t s_phaseStart     = 0;
static uint32_t s_lastUi         = 0;
static uint8_t  s_sweepsSinceBle = 0;
static uint8_t  s_sweepsSince2G  = 0;

static const char* phaseLabel(Phase p) {
    switch (p) {
        case PHASE_WIFI_5G: return "5GHz WiFi";
        case PHASE_WIFI_2G: return "2.4GHz WiFi";
        case PHASE_BLE:     return "BLE";
    }
    return "?";
}

// Stopping both unconditionally is safe - each stop function is a no-op if
// that stack isn't the one currently up.
static void switchToPhase(Phase next) {
    detectorStopWifiPhase();
    detectorStopBlePhase();

    switch (next) {
        case PHASE_WIFI_5G: detectorStartWifi5GPhase(); break;
        case PHASE_WIFI_2G: detectorStartWifi2GPhase(); break;
        case PHASE_BLE:     detectorStartBlePhase();    break;
    }

    s_phase      = next;
    s_phaseStart = millis();
}

// Decide what follows a completed 5GHz sweep: a rare 2.4GHz token check, an
// occasional short BLE dip, or straight into another 5GHz sweep (the common
// case - 5GHz is the dominant phase by design).
static Phase pickAfter5G() {
    s_sweepsSinceBle++;
    s_sweepsSince2G++;

    if (s_sweepsSince2G >= WIFI_2G_EVERY_N_SWEEPS) {
        s_sweepsSince2G = 0;
        return PHASE_WIFI_2G;
    }
    if (s_sweepsSinceBle >= BLE_EVERY_N_SWEEPS) {
        s_sweepsSinceBle = 0;
        return PHASE_BLE;
    }
    return PHASE_WIFI_5G;
}

void setup() {
    Serial.begin(115200);

    uiInit();
    uiBootScreen();

    alertInit();
    detectorInit();

    switchToPhase(PHASE_WIFI_5G);
}

void loop() {
    uint32_t now = millis();

    uint32_t phaseDuration;
    switch (s_phase) {
        case PHASE_WIFI_5G: detectorHopChannel(); phaseDuration = WIFI_5G_PHASE_MS; break;
        case PHASE_WIFI_2G: detectorHopChannel(); phaseDuration = WIFI_2G_PHASE_MS; break;
        default:             /* PHASE_BLE */       phaseDuration = BLE_PHASE_MS;     break;
    }

    if (now - s_phaseStart >= phaseDuration) {
        if (s_phase == PHASE_WIFI_5G) {
            Phase next = pickAfter5G();
            if (next == PHASE_WIFI_5G) {
                // Staying in 5GHz for another sweep - the radio's already
                // up and tuned, just reset the phase timer. Going through
                // switchToPhase() here would tear down and reinit the WiFi
                // stack for no reason every single sweep.
                s_phaseStart = now;
            } else {
                switchToPhase(next);
            }
        } else {
            switchToPhase(PHASE_WIFI_5G);
        }
    }

    detectorExpire();

    DetectorStatus st = detectorStatus();
    alertUpdate(st, ALERT_HOLD_MS);

    // Display is comparatively slow, so throttle it.
    if (now - s_lastUi >= UI_REFRESH_MS) {
        uiRender(st, phaseLabel(s_phase));
        s_lastUi = now;
    }
}

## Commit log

2026-09-15 Set up C5 fork: drop PlatformIO config, isolate legacy sources
    PlatformIO has no esp32c5 support, so this fork builds via Arduino IDE
    instead - platformio.ini no longer applies.
    detector.cpp, ui.cpp, main.cpp, and config.h are the original ESP32 /
    2.4 GHz-only / u8g2 implementations; they need a genuine rework for the
    XIAO ESP32-C5 (5 GHz, three-band phase machine, ILI9341 colour UI, SD
    config) rather than incremental patching, so they move to legacy/ as
    reference instead of staying in src/include where they'd look current.
    CLAUDE.md carries fork-specific research (barracks location/coordinates,
    captured MACs) and is gitignored to stay local-only even though this repo
    is public.
    Co-Author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
    [config.h, main.cpp, ui.cpp]
2026-09-18 Bring up XIAO ESP32-C5 hardware and build the real detector firmware
    Bring-up steps 1-3 (blink, display, buzzer) passed individually on real
    hardware. Step 4 (5GHz promiscuous scan, the fork's core premise) was
    proven on the bench using a real ambient AP, correctly decoded end to
    end - band switching, promiscuous capture, channel hopping, and 802.11
    frame parsing all work on this chip. Field validation against the actual
    target hardware is still pending.
    Once that risk was retired, moved straight to building the integrated
    firmware in firmware/le_detector_c5/ instead of continuing granular
    one-sketch-per-step bring-up. Ported the scanning/matching core from
    legacy/detector.cpp - TrackedDevi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
    [01_blink_test.ino, 02_display_test.ino, 04_5ghz_promiscuous.ino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]
2026-09-18 Add BIXOLON, Vantiva OUIs and SP-MVR SSID to the watchlist
    Three gaps flagged in prior research but never closed: BIXOLON
    (00:15:94, in-car citation printer) and Vantiva (0C:FE:7B, matches
    in-vehicle router naming) as OUI entries, and SP-MVR as a second SSID
    prefix alongside PSP-MVR (confirmed as a genuinely distinct SSID on
    paired virtual APs, not a typo). Table now 64 OUI / 6 SSID entries, up
    from 62/5. Added matching test_oui.cpp assertions for both new OUIs.
    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
2026-10-01 Rework duty cycle to be 5GHz-dominant, add band labeling to alerts
    5GHz sweeps continuously in clean passes (one sweep = 2700ms, down
    from 1.5 sweeps' worth); a 400ms BLE dip and a 3-channel 2.4GHz token
    check (1/6/11, not the full 1-11) are now rare interjections every 3rd
    and 8th sweep respectively, instead of running every single cycle. The
    phase machine no longer tears down/reinits the WiFi stack when just
    continuing another 5GHz sweep back-to-back.
    Based on real drive data from a separate analysis session: 5GHz is the
    only long-range continuous signal and should dominate; BLE's realistic
    job is a stopped/close encounter lasting seconds, not a sub-second
    highway pass, so it doesn't need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
    [05_radio_switch_timing.ino, config.h, le_detector_c5.ino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]
2026-10-02 Rewrite README.md for the C5 fork
    Was completely unmodified from the original ESP32-WROOM-32U/PlatformIO
    project - wrong title, wrong build system (PlatformIO has no C5
    support), wrong pins, wrong parts list, described an LED that doesn't
    exist in this design, stale watchlist counts, and a 66-row OUI table
    that had already drifted out of sync with the source.
    Replaced the hand-duplicated OUI table with an equipment-type summary
    and a link to oui_table.cpp as the source of truth, plus an explicit
    list of what's disabled by default and why - the table had already
    proven it drifts in practice (this fork alone added 3 entries and
    disabled 2 without ever touching the README copy). Generalized th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
2026-10-03 Add WIP carrier PCB design and 3D-printable case files
    Both explicitly work in progress - not finished, not ready to
    fabricate. Marked clearly with a README in each directory.
    case/: Tinkercad-exported enclosure, built and tested with
    breadboard/jumper wiring (confirmed everything fits). Width/height
    are final (matched to the display's own 50x86mm footprint, lid
    already has a viewing window cut for it); depth will be trimmed once
    the carrier PCB's actual stack height is known.
    hardware/carrier_pcb/: first-draft KiCad 10 schematic + PCB footprint
    layout for a board the XIAO/display/buzzer socket into (true female
    headers), sized to fit the case above. Schematic is complete and
    ERC-clean. PC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
    [Extended_case.stl, Lid.stl, bom.csv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]
2026-10-03 Carrier PCB: drop mounting holes, chamfer corners instead (still WIP)
    The first draft gave the carrier board the same 4 mounting holes as the
    display, so it could share the case's corner bosses - but that means
    stacking two boards on the same 4 screws, which needs standoffs/spacers
    and a deeper case boss to clear the header pins. Not worth the case
    modification for an assembly this light.
    Board now has no mounting holes at all - it's held by its header
    engagement with the display board above it (which keeps screwing to the
    case exactly as before). Hot glue is the cheap fallback if vibration
    ever proves that insufficient. Each corner is chamfered (6mm legs)
    instead, since the case's corner b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
    [carrier_pcb.kicad_pcb]
2026-10-03 Ignore KiCad's transient .kicad_pro.lck file
    Claude-Session: https://claude.ai/code/session_017xhV7dmwhHCLCtBdydJWwW
2026-10-03 Carrier PCB: keep J2 socket, remove its wiring
    J2 (the display's SD header) was wired onto the shared SPI bus in the
    very first schematic draft without ever being its own discussed
    decision - it rode along under "the display plugs into the front" as
    if that meant all of the display's headers, which was never actually
    agreed. SD bring-up is a real future goal but isn't happening yet, so
    there's no reason to carry live connections for it now.
    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
    [bom.csv, carrier_pcb.kicad_pcb, carrier_pcb.kicad_sch]
2026-10-03 Carrier PCB: correct J2 position, confirm 2-layer routing is unrestricted
    J2's placement (18.40, 11.00) was a rough visual estimate off the
    MSP2807 datasheet image. Re-measuring it found the real bug: the
    original pixel-to-mm conversion assumed the PDF rendered at a literal
    1:1 300dpi-to-mm scale. Solving for the actual scale against the two
    known hole-spacing dimensions (44.00mm, 76.08mm) gives ~9.05px/mm, not
    ~11.81 - about 23% off. Corrected position is (21.15, 4.96): the SD
    pads sit at essentially the same height as the top mounting holes, not
    ~11mm down. Pitch was already right (2.54mm).
    Also cleaned up a stale comment in the PCB generator implying routing
    would stay on one copper laye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
    [carrier_pcb.kicad_pcb]
2026-10-03 Carrier PCB: routing complete, DRC-clean
    Routed interactively in the KiCad GUI (push-and-shove, live DRC), using
    vias to hop layers at the two nets that shorted in the earlier
    automated attempt (TFT_SCK/TFT_CS, TFT_MOSI/TFT_DC). Verified both in
    the GUI (F8) and independently via kicad-cli pcb drc: 0 errors, 0
    unconnected items - the only warnings are the same cosmetic baseline
    seen throughout this project (missing-footprint-library notices, two
    non-mirrored back-layer reference texts).
    Also ignore KiCad's local backup zips and lock files generically
    (*.lck, *-backups/) rather than just the one .kicad_pro.lck pattern.
    Claude-Session: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
    [carrier_pcb.kicad_pcb]
2026-10-03 Carrier PCB: chamfer -> square notch, sized against the real boss
    User printed the board at true 1:1 scale and physically test-fit it
    against the case: the 6mm diagonal chamfer wasn't close to clearing the
    real mounting boss. Measured the boss properly off the case STL via a
    top-down render self-calibrated against the model's own exact bounding
    box (not an assumed scale) - it's a rounded square roughly 7-8mm
    across, not the slim post the chamfer was sized against.
    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
    [carrier_pcb.kicad_pcb]
2026-10-03 Carrier PCB: fix print-to-scale by matching PDF page size to US Letter
    User's 1:1 scale printout measured 30.7mm on a feature that should be
    33.02mm (J1's pin span) - about 93% scale despite the print dialog set
    to 100%. Root cause: the PDF export used KiCad's default A4 page size,
    and printing an A4-sized PDF on US Letter paper gets silently shrunk by
    some print drivers to fit the printable area (297mm A4 width doesn't
    fit on Letter's 279.4mm) regardless of the requested percentage.
    279.4/297=0.941, matching the ~93% observed closely.
    Fixed by changing (paper "A4") to (paper "USLetter") in the board file
    so the exported PDF's page size matches the paper actually going
    through the printer.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
    [carrier_pcb.kicad_pcb]
2026-10-03 Carrier PCB: narrow the board to fit between the bosses instead of notching around them
    The square notch (7.3mm, previous commit) topped out capped by J1's own
    pad clearance - still ~1mm short of what the measured boss actually
    needed, an unresolved gap. User's fix: stop designing a cutout shape to
    dodge the bosses and just make the board narrow enough to never reach
    them. Measured the case's real clear channel between the two bosses:
    36.3mm (the board's 86mm length was never tight, only the width).
    Board outline is now a plain rectangle, 36.3x86mm, centered on J1 (the
    single widest feature at 33.02mm pin span) instead of matching the
    display's full 50mm width. No corner notches needed. J1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
    [carrier_pcb.kicad_pcb]
2026-10-03 Carrier PCB: trim top edge so J2 sits on the board edge, mirroring J1
    J1 sits 2.0mm (pin-center-to-edge) from the bottom edge. J2 was still
    4.96mm from the top edge, leaving unused board above it. Pulled the top
    edge in to match J1's exact margin - new top at y=2.96 (was y=0), board
    now 36.3x83.04mm (was 36.3x86mm).
    Same 1.40mm copper-to-edge clearance J1 already had. Checked before
    editing that no routed track/via falls in the trimmed region - all 64
    segments preserved. DRC clean (0 errors, 0 unconnected, same cosmetic
    baseline) after.
    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
    [carrier_pcb.kicad_pcb]
2026-10-03 Carrier PCB: fix U1 footprint to match the real XIAO ESP32-C5, clear routing
    U1's footprint was a generic guess - two rows of 7 pins, 7.62mm apart,
    naive i*2.54mm spacing - never checked against the real part, and not
    mirrored for the fact that it mounts on this board's back (opposite
    the display). User caught both problems.
    Fixed using Seeed's own official KiCad library files (downloaded from
    their XIAO KiCad library page, which covers the whole XIAO family):
    - Real row spacing is 15.24mm, not 7.62mm - the old footprint used
    entirely the wrong part of the board.
    - Cross-referenced the matching schematic symbol for the real
    pin-number-to-signal mapping (D0-D6 on one row; D7-D10 plus
    3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
    [carrier_pcb.kicad_pcb]
2026-10-03 Carrier PCB: reorder J3 pins to match real buzzer, slide U1 for USB-C clearance
    J3 (buzzer) was VCC/GND/SIG on pins 1/2/3 - reordered to GND/SIG/VCC to
    match the real buzzer module's actual pinout. Pad positions unchanged,
    only the net on each pad (schematic labels + PCB pad nets); symbol's
    own pin names updated too so it doesn't visually lie about what's wired
    where.
    U1 slid from center (x=25) toward the board's right edge for USB-C
    cable clearance. Checked the real device's physical body against the
    board edge, not just its pads - the official footprint's courtyard
    extends ~2.8mm past the pin span on each side, so a naive pads-only
    check would have let the real part hang ~1.3mm off the ed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
    [carrier_pcb.kicad_pcb, carrier_pcb.kicad_sch]
2026-10-03 Carrier PCB: slide J3 left for U1 clearance, switch to right-angle header
    J3 moved from x=20 to x=9, clear of both the board's left edge (1.55mm
    pad clearance) and U1's real device courtyard (6.77mm clear at U1's
    body edge, now that U1 sits further right). DRC clean after.
    Switched J3's BOM entry to a right-angle (90-degree) female header so
    the buzzer module can lie flat against the carrier instead of standing
    up on pins - same 3-pad footprint, just a different part populated
    there. Updated BOM.md, bom.csv, and the schematic's Description
    property for J3.
    Deliberately did not pick a standoff height. The buzzer board needs to
    clear a USB-C cable plugged into U1, but that depends on real
    me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
    [bom.csv, carrier_pcb.kicad_pcb, carrier_pcb.kicad_sch]
2026-10-03 Carrier PCB: add silkscreen labels + pin-1 markers, fix a real mirror bug
    Added functional labels to all 4 connectors stating what they are and
    which side they mount on (DISPLAY/FRONT, SD-NC/FRONT, XIAO/BACK,
    BUZZER/BACK), plus square pin-1 pads on all 4 connectors as a
    consistent orientation cue - this board has already had two real
    orientation bugs this session (U1 mirroring, J3 pin order).
    While verifying the new back-side labels, found that DRC's
    nonmirrored_text_on_back_layer warning on U1/J3's reference labels -
    present since they were first created, dismissed every time as the
    same cosmetic baseline as the library-name warnings - was flagging a
    real bug. Rendering with kicad-cli's -m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
    [carrier_pcb.kicad_pcb]
2026-10-03 Carrier PCB: add board title "LE Detector C5 by datafx"
    Placed on the back (B.SilkS), not the front - the display plugs into
    J1 and is nearly the carrier's full height, covering almost the entire
    front face once assembled, so front silkscreen there would be hidden
    after the fact. The back stays mostly open even with U1/J3 populated.
    2.2mm text (vs 1mm for the connector labels), vertical along the left
    edge, rotated 90 degrees to read top-to-bottom, positioned clear of
    both U1 and J3. Added the mirror flag from the start (lesson from the
    previous commit) and verified with a true flipped-back render before
    trusting it - reads correctly, not backwards.
    DRC clean: 0 errors, same 4 expected lib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
    [carrier_pcb.kicad_pcb]
2026-10-03 Carrier PCB: re-routed after U1/J3/outline fixes, solder sides verified
    Routed all nets again in the KiCad GUI following the earlier footprint
    and outline corrections (U1's real geometry + mirroring, J3's pin
    order, the narrowed board). 41 segments (down from the original 64,
    shorter runs now that U1 sits close to everything else). DRC clean: 0
    errors, 0 unconnected items, same 4-item cosmetic baseline.
    Verified each connector's solder side directly from the footprint's
    stored layer field rather than relying on a visual check alone: J1/J2
    on F.Cu (front), U1/J3 on B.Cu (back) - matches every silkscreen label.
    Claude-Session: https://c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
    [carrier_pcb.kicad_pcb]
2026-10-03 Carrier PCB: add the missing J2 mating header to the BOM
    The MSP2807 display ships with its SD-header pads unpopulated - there's
    nothing there to plug into J2 as-is. Needed purely for mechanical
    support (J2 carries no signals), but it's a real part: a 1x4 straight
    male header, 2.54mm pitch, has to be hand-soldered onto the display
    board itself before assembly works.
    Added to BOM.md under a new "Parts needed on the display module itself"
    section, separate from the carrier-PCB-mounted parts table since this
    part lives on the display board, not the carrier. Noted the same in the
    README's J2 section.
    Claude-Session: https://claude.ai/code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
2026-10-03 Ignore generated gerber/drill fab outputs
    Same reasoning as the 1:1 printout PDF - these are 100% derived from
    the tracked .kicad_pcb source and go stale the moment the board
    changes, so there's nothing to gain from version-controlling the
    output itself.
    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
2026-10-16 Fix boot screen text overlap, extend display time, recalibrate RSSI scale
    Boot screen: the combined "WiFi 5GHz: N ch, 2.4GHz: N ch (token)" line
    ran ~37 characters at text size 2 against a ~24-character-wide screen,
    silently word-wrapping and landing on top of the "Starting..." line
    drawn right below it - the overlap the user was seeing. Split into two
    short lines, each safely under the per-line width budget, and switched
    to a running Y cursor instead of hardcoded offsets so line spacing
    can't silently drift out of sync again. Also disabled text wrap
    globally (tft.setTextWrap(false)) as a defensive baseline - if a
    future line ever runs long again, it clips instead of silently
    overlapping wha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
2026-10-16 Pick up incidental KiCad GUI settings drift in carrier_pcb.kicad_pro
    Teardrop td_enabled flags and net_colors/netclass_assignments
    (null -> {}) - standard KiCad-written defaults from the project being
    open in the GUI, not an intentional design change.
    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
2026-10-16 Carrier PCB: extend board 2mm, move J3 closer to J1 - fixes from physical build
    First hands-on assembly surfaced two real issues the digital fit/DRC
    couldn't catch:
    Board too short - with the top edge trimmed to match J2's 2mm margin
    (the earlier "J2 sits on the edge like J1" change), there wasn't
    enough board material left above J2 to keep the display flush once
    both headers (J1 + J2, no mounting holes) were seated - it sat
    tilted. Extended the top edge back out by 2mm (y=2.96 -> y=0.96,
    board now 36.3x85.04mm, was 83.04mm). Pure outline growth, zero risk
    to existing routing.
    XIAO's real USB-C connector crowded J3's right-angle header in
    practice - not modeled by courtyard-only clearance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
2026-10-16 Carrier PCB: actually fix the tilt - move J2, not just the board edge
    The previous commit (aa9d4ae) extended the board outline by 2mm but
    never moved J2's own pad position - since J1-to-J2 spacing (the thing
    that actually determines whether the real display's two headers line
    up straight) never changed, that edit couldn't have fixed the tilt at
    all, just made the board bigger around the same misalignment. Caught
    immediately by the user.
    Real fix: moved J2 the same 2mm, same direction, right along with the
    edge (y=4.96 -> 2.96) - not just grown the board around it. Restores
    J2's margin-from-edge to exactly 2.0mm (matching J1's margin, the
    original "J2 sits on the edge like J1" relationship)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
2026-10-16 Carrier PCB: mark Rev 2 on silkscreen title
    Appended " Rev 2" to the board title now that this revision's fixes
    (board length, J2 spacing, J3 position, full routing) have landed -
    traceability for a built board against which design it matches.
    Re-verified the same way the title was first added: DRC clean after
    (0 errors, 0 unconnected items), and a true flipped-back render (-m
    flag) confirms the longer string still reads correctly top-to-bottom
    with no new collisions - J3 moved further away since this text was
    first placed, so there was more room to work with, not less.
    Claude-Session: https://claude.ai/code/session_017xhV7dmwhHCLCtBd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
2026-10-16 Case: add GoPro-style mount and USB panel connector cutout
    Updates Extended_case.stl - adds a GoPro-style mount tab (extends the
    case body ~23mm in length) and cutout holes for a panel-mount USB-C
    connector, mentioned in the project's own notes as a planned feature
    with a cutout already reserved but not yet designed. Main case body
    dimensions (90mm width, 41.8mm height) unchanged.
    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
2026-10-16 Note the GoPro mount + USB panel cutout addition in case/README.md
    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
2026-10-16 Credit the original case design in case/README.md
    Links to the Printables model this case is based on. Couldn't pull the
    exact author name/license automatically (page returns 403 to automated
    fetches) - credited via the model link itself.
    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
2026-10-17 Create the default event loop so WiFi stops logging on every hop
    detector.cpp drives esp_wifi directly (no Arduino WiFi library), so the
    default event loop was never created and the WiFi driver logged
    "failed to post WiFi event=43 ret=259" on every channel hop, not just at
    band transitions as previously noted. Nothing listens for these events;
    the loop just has to exist. One esp_event_loop_create_default() call in
    detectorInit().
    Found and verified on the Waveshare port (datafx/le_detector_waveshare_c5),
    where 40s of serial went from ~3 errors/s to zero. Here: compile-checked
    only, since the XIAO wasn't connected.
2026-10-17 README: add confirmed agencies and contributing sections
    Same sections as the Waveshare port: PSP is the only field-confirmed
    agency, but any agency running in-car Axon WiFi APs should match the
    same OUI. Contributing asks for Kismet captures near police vehicles
    (multiple samples from different areas), shared privately via a GitHub
    issue first.
